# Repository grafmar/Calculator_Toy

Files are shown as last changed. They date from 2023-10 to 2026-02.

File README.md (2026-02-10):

# Calculator_Toy
Device for kids which generates math equations to solve. You can configure the following:
- Set the maximum numbers too choose from randomly (1 up to 9999)
- Set the operation to build:
  - Addition (+)
  - Substraction (-)
  - Multiplication (*)
  - Division (:)

## Required SW
* [Arduino IDE](https://www.arduino.cc/en/main/software)
* Adafruit_GFX library
* Adafruit SSD1306 library
* Keypad library

## Hardware
The hardware consists of:
* Perfboard 7x9 cm
* [Arduino Nano](https://store.arduino.cc/collections/nano-family/products/arduino-nano)
* [0.96" SSD1306 OLED display](https://www.aliexpress.com/w/wholesale-ssd1306.html)
* Tactile push buttons 6x6x8mm
* [Push Button Switch 7x7x12mm](https://www.aliexpress.com/item/32826123110.html)
* Buzzer

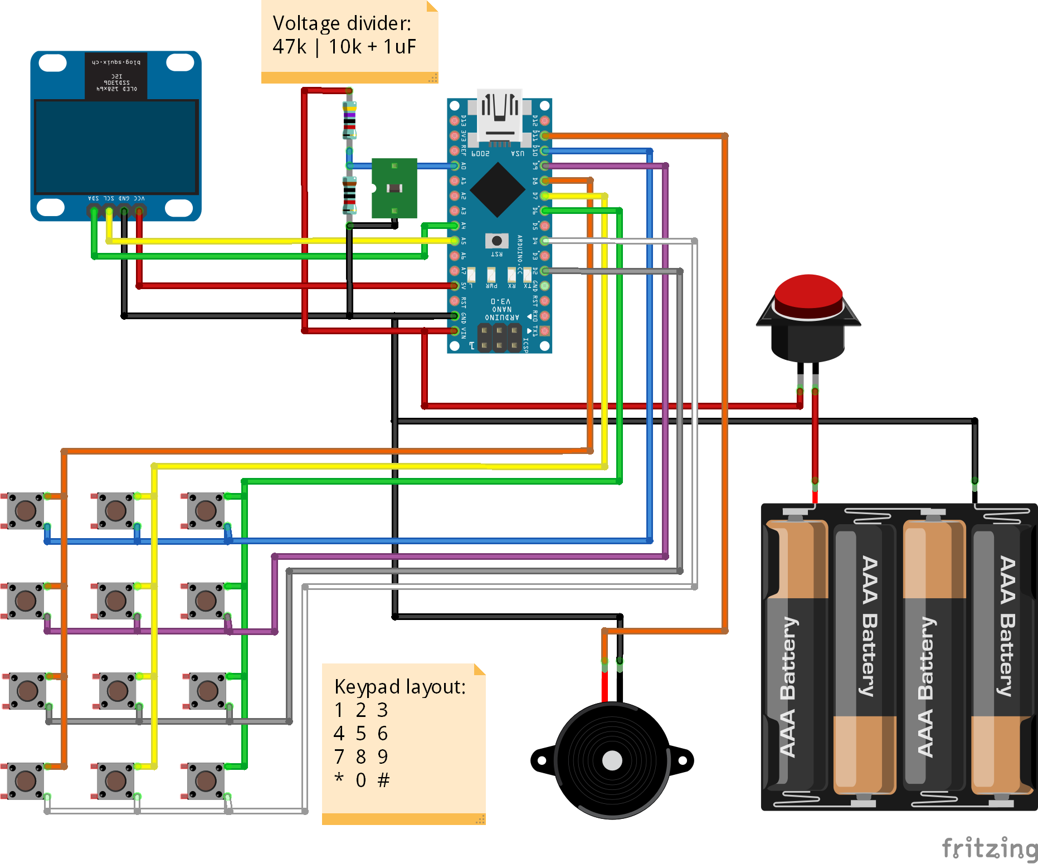
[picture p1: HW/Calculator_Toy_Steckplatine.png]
Wiring of hardware
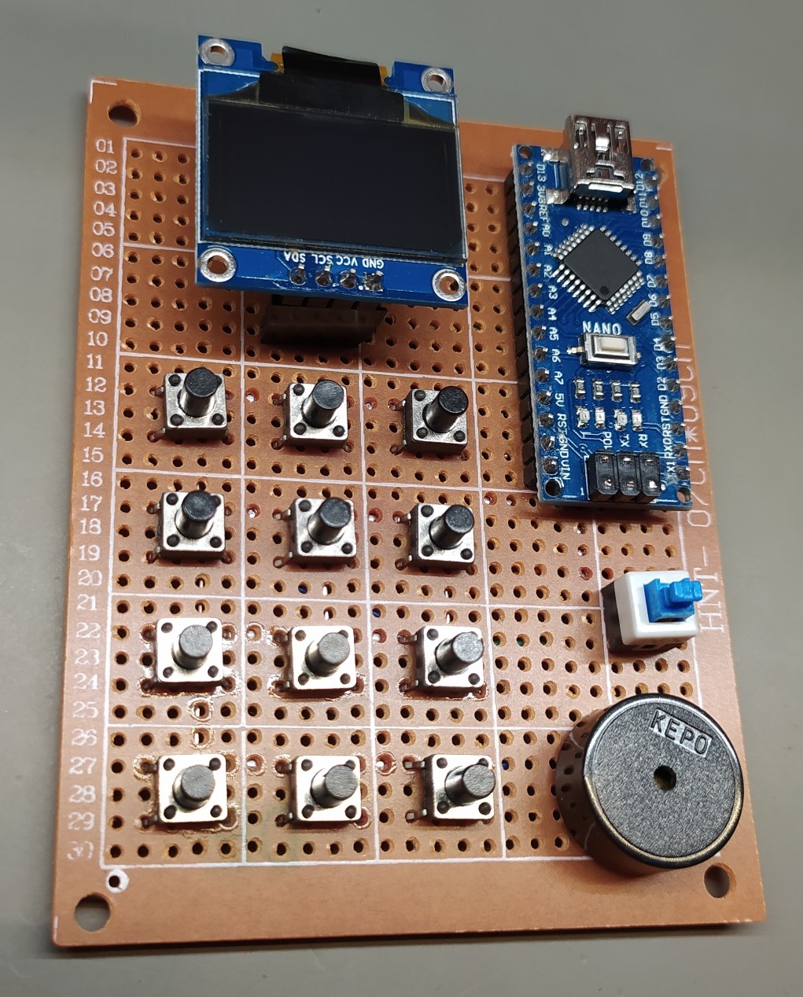
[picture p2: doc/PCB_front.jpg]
PCB front
 <br>

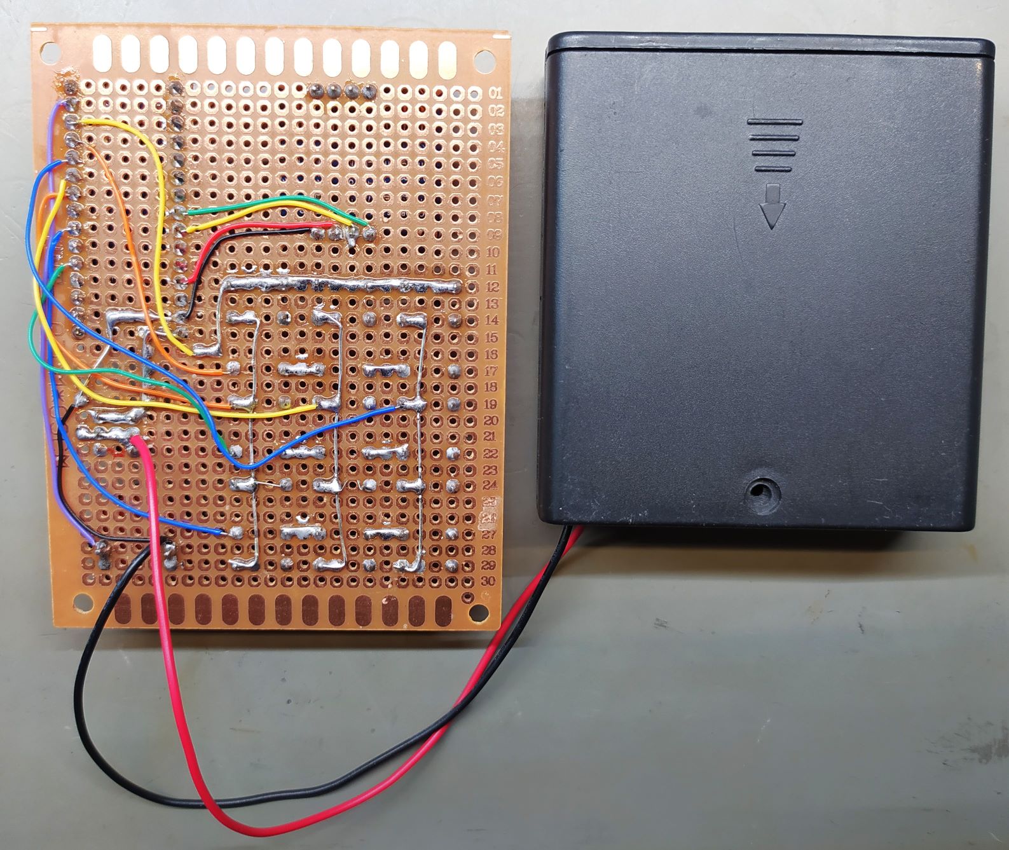
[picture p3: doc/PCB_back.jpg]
PCB back
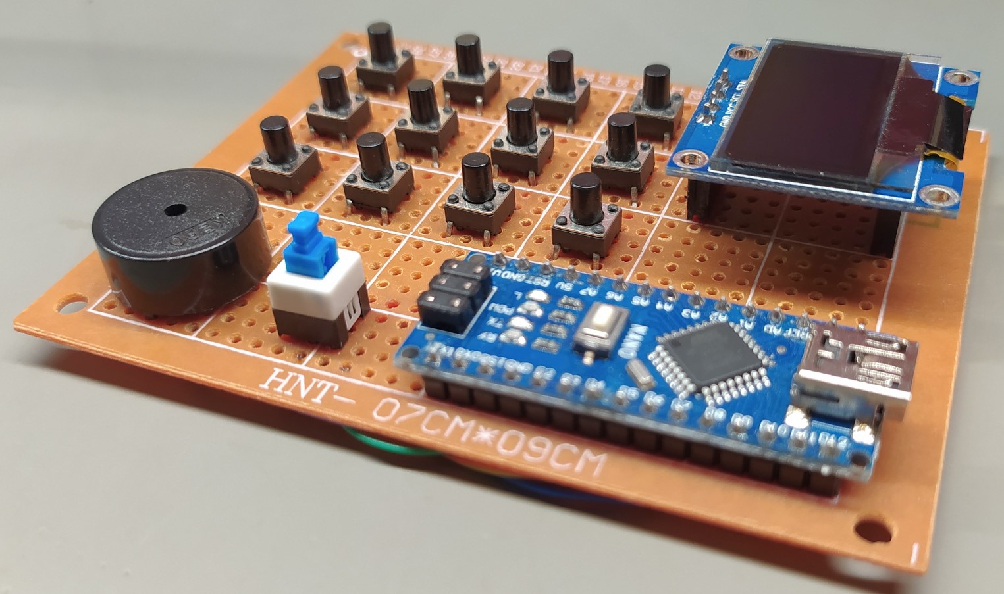
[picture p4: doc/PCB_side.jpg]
PCB side
 

The Display is supported with an additional pin-header on top, so the display is flush
to the housing.

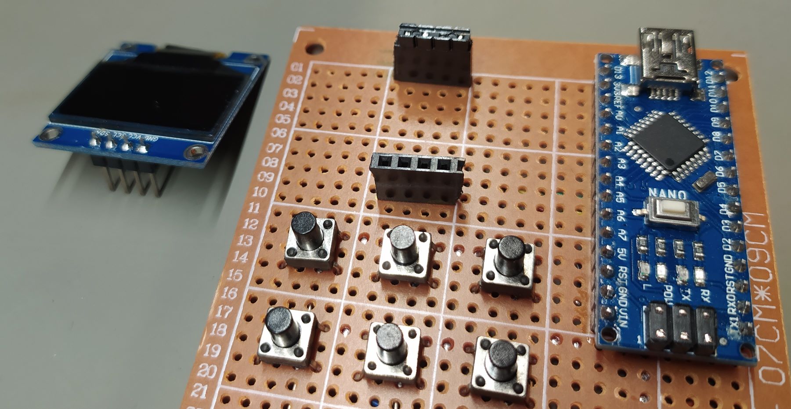
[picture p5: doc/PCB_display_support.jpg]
Display support


To monitor the battery a voltage divider has been added from Vin to the analog input A0
with 47k and 10k resistors and a 1uF capacitor.

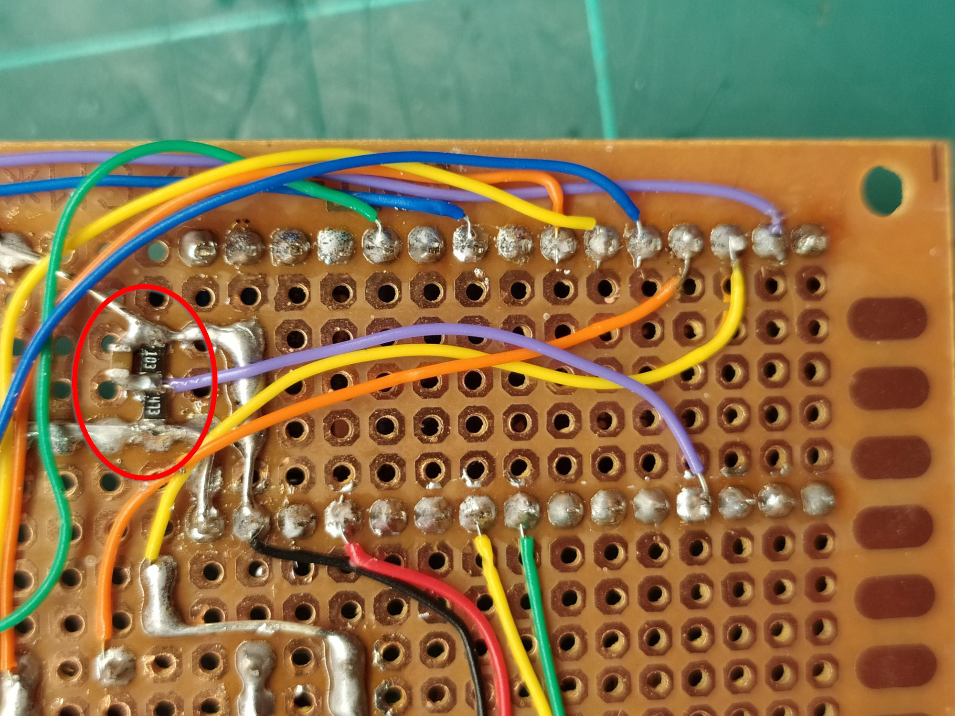
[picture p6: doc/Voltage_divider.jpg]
Added voltage divier


## Software
The software is compiled in Arduino IDE and uploaded to the Arduino Nano.
It was tricky to fit all the things into the memory of the Arduino Nano.

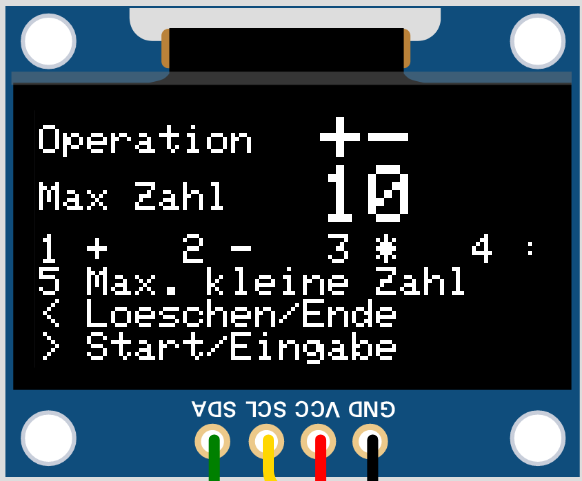
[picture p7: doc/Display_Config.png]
Display Config


First the configuration screeen is shown to configure which operations are used in the
game and how big the numbers may be. For the operations it can be choosen from plus,
minus, multiplication and division. The number-space is defined by defining the maximum
small numbers. So the sum, the minuend, the dividend and product may be bigger.

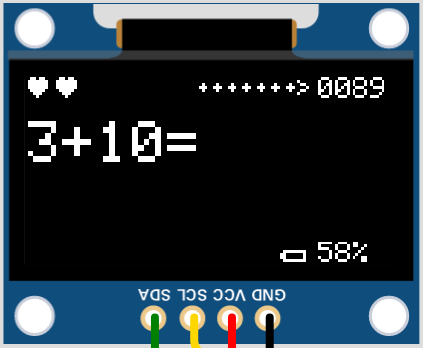
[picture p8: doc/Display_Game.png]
Display Game


Then the calculation game is started. There are three lives represented as hearts. If an
answer of the calculation is wrong, it costs a live. If the calculation is right, points
are earned. This depends on the time used to solve the calculation. Besides the score points
are shown which decrease the more time is needed. The remaining points are added to the
score if the right answer is given.

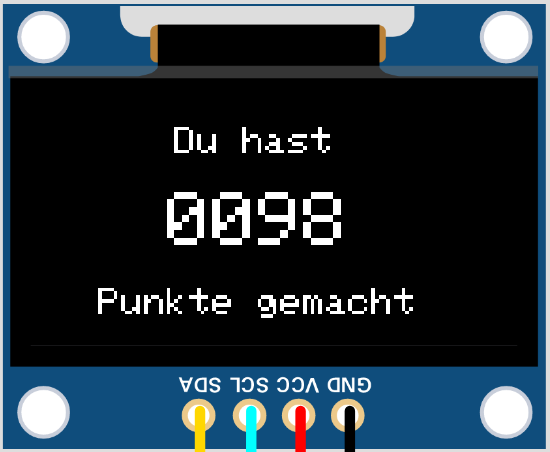
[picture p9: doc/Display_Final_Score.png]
Display Final Score


If the all lives were lost, the reached score is shown.

[Here is a life simulation of the circuit and code](https://wokwi.com/projects/378812103614159873)

## Housing / Enclosure
The housing is created with a sliding back to close the housing and support the PCB
for any button presses. The Buttons are designed with engraved numbers and symbols.

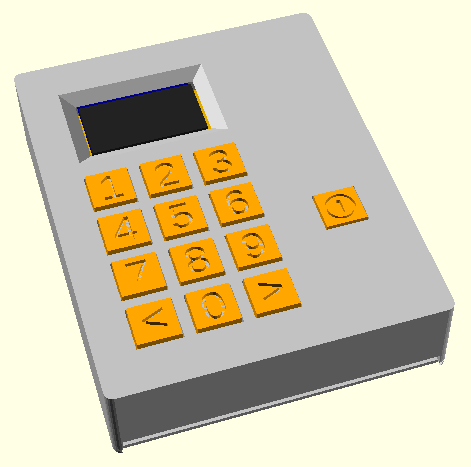
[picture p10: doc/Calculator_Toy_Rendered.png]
Rendered Housing
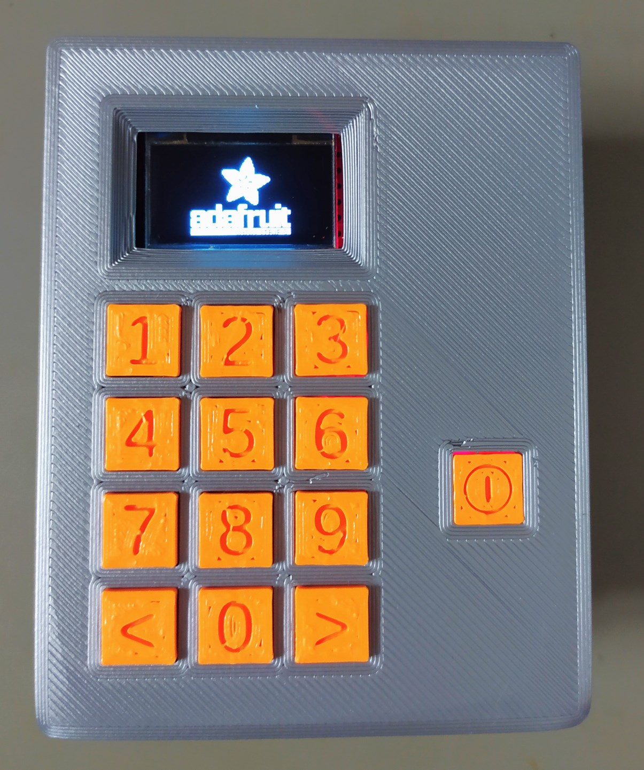
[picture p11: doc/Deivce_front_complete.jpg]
Finished device
 <br>

Added a lid to screw the housing shut and used filament change to add a second color for the inlets of the keys.

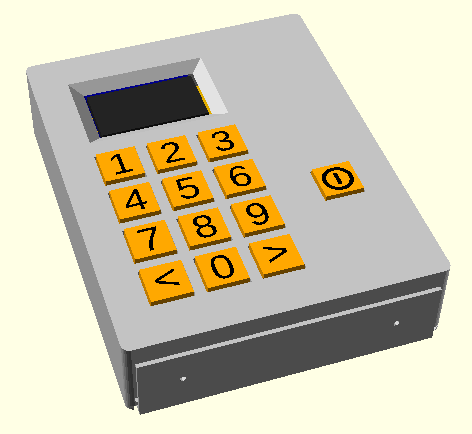
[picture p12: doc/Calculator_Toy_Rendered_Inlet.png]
Rendered Housing with inlet keys
<br>

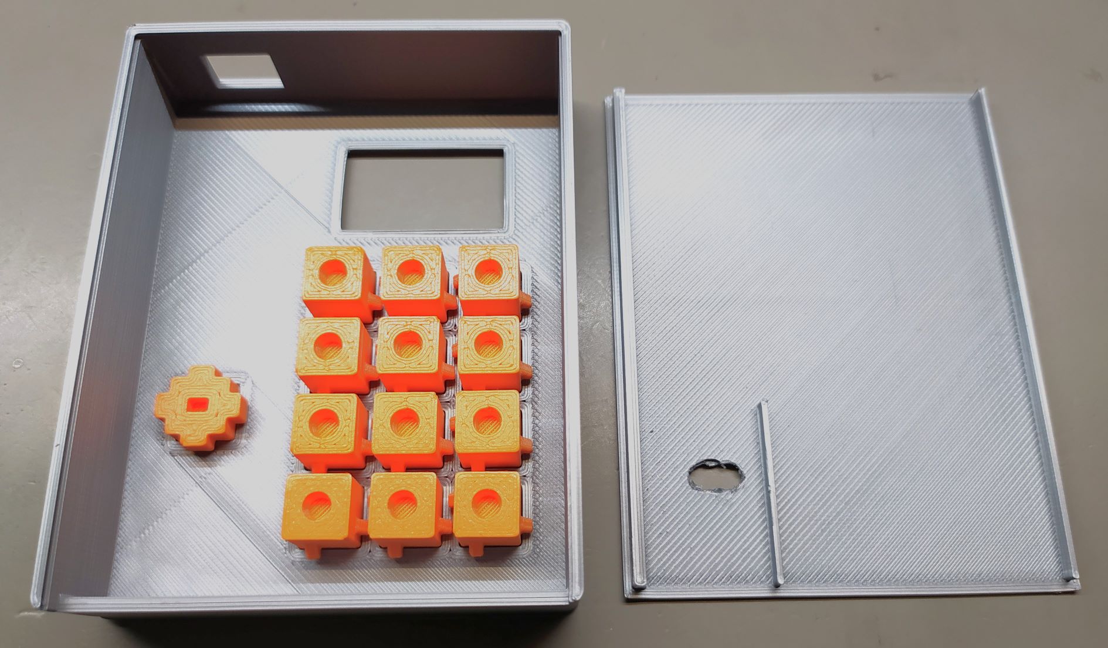
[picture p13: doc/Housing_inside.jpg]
Housing inside
<br>

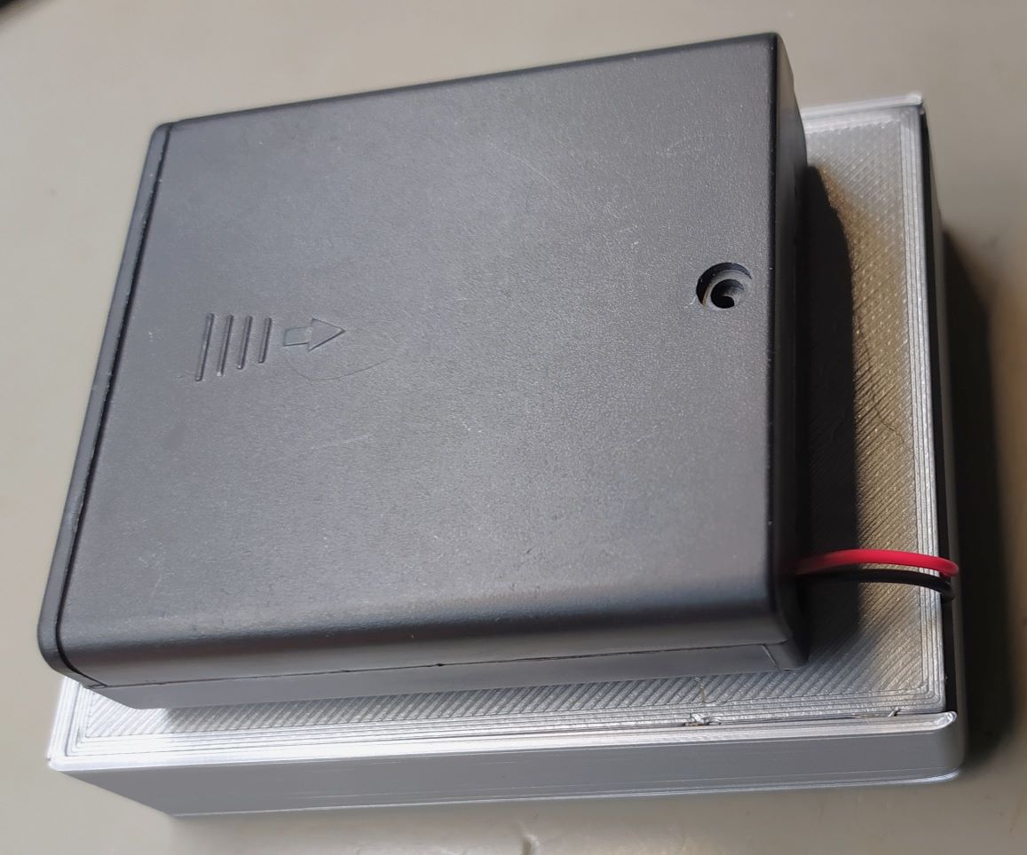
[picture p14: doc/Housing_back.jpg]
Housing back
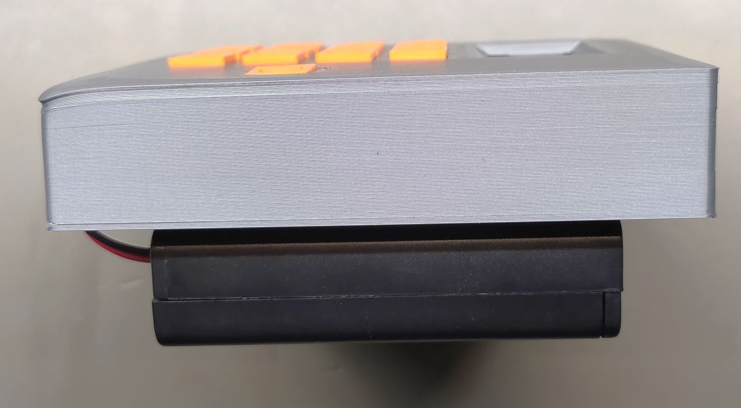
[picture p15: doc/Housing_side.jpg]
Housing side
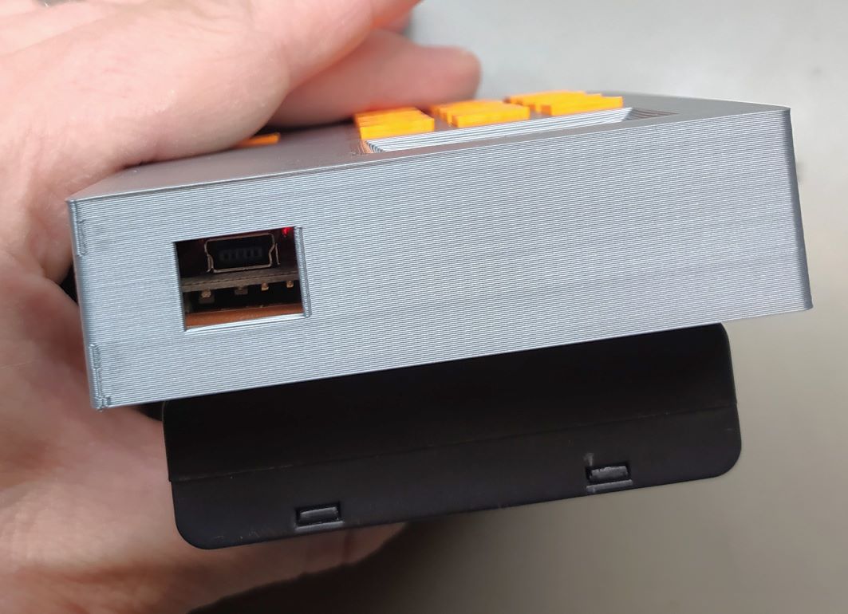
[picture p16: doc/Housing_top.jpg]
Housing top
  

## Author
[Marco Graf](https://github.com/grafmar)

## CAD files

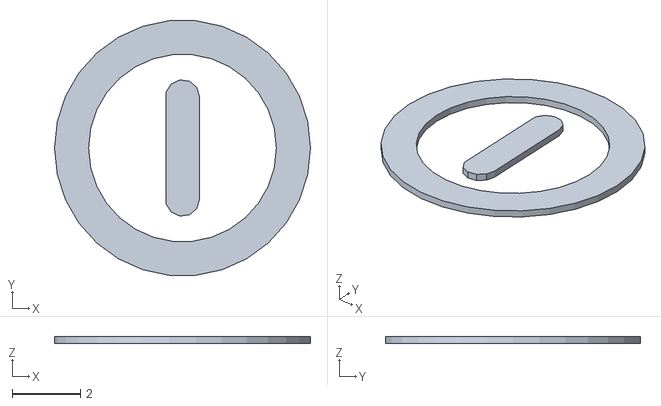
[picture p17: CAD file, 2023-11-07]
Housing/Calculator_Toy_OnOffSwitch_Inlet.stl
7.50 x 7.46 x 0.2

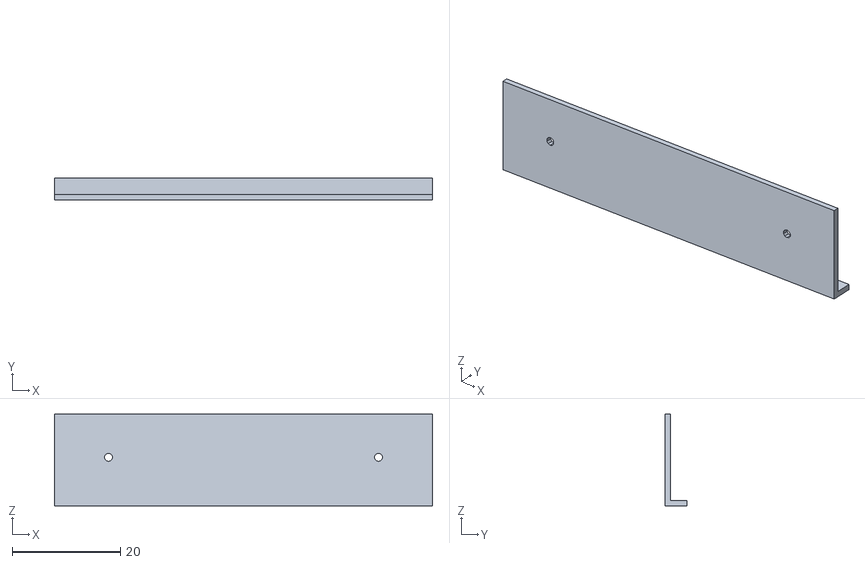
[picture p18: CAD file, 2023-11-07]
Housing/Calculator_Toy_Housing_closingLid.stl
70.0 x 4.00 x 17.0

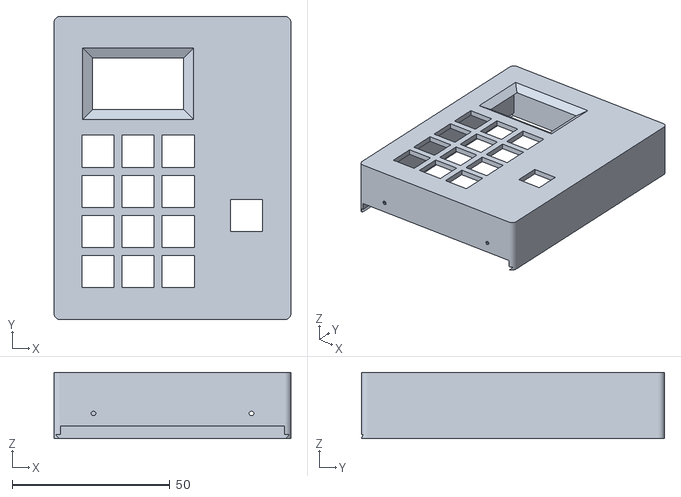
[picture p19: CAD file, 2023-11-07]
Housing/Calculator_Toy_Housing_Housing.stl
75.0 x 96.0 x 21.0

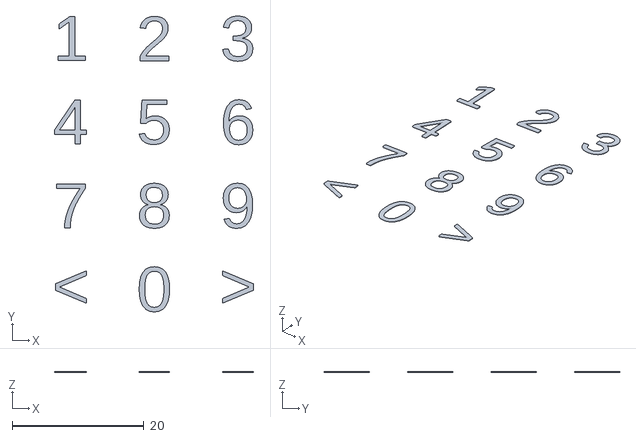
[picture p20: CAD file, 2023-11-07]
Housing/Calculator_Toy_Keypad_Inlet.stl
30.2 x 45.0 x 0.2

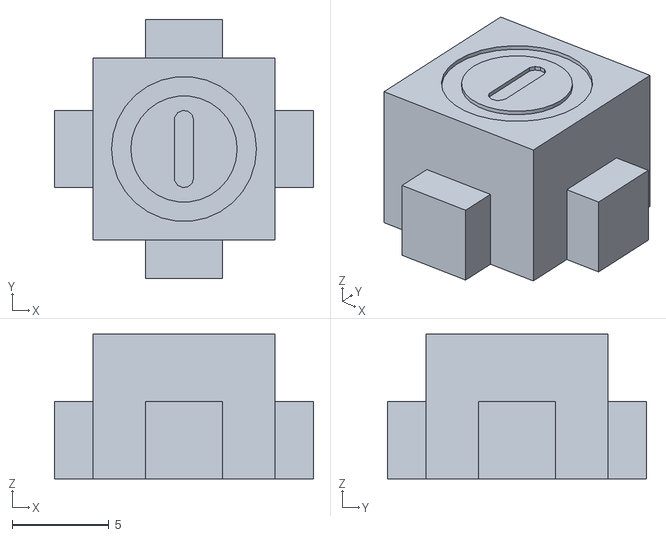
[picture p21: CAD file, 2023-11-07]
Housing/Calculator_Toy_OnOffSwitch_ForInlet.stl
13.4 x 13.4 x 7.50

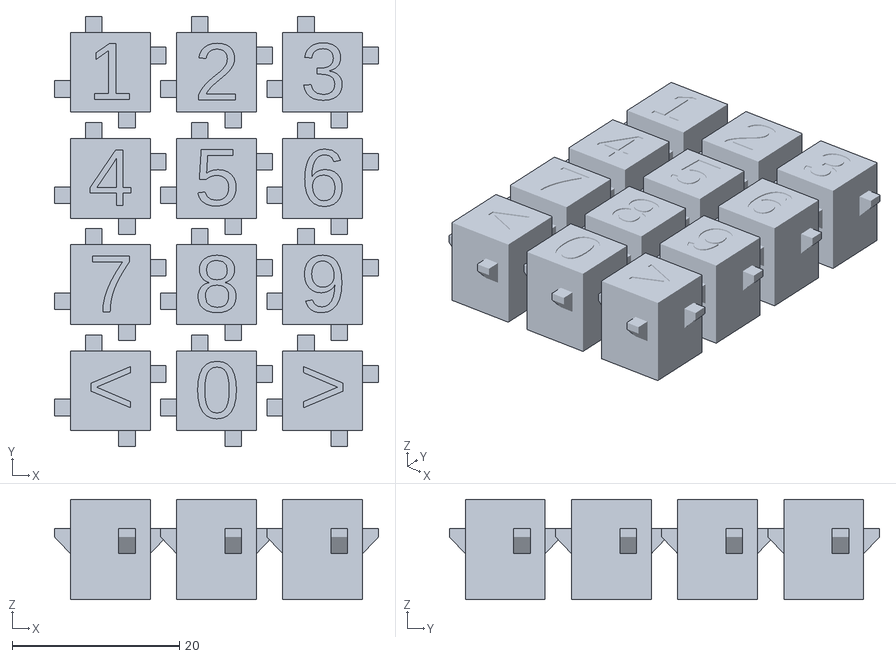
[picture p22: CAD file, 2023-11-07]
Housing/Calculator_Toy_Keypad_ForInlet.stl
38.8 x 51.5 x 12.0

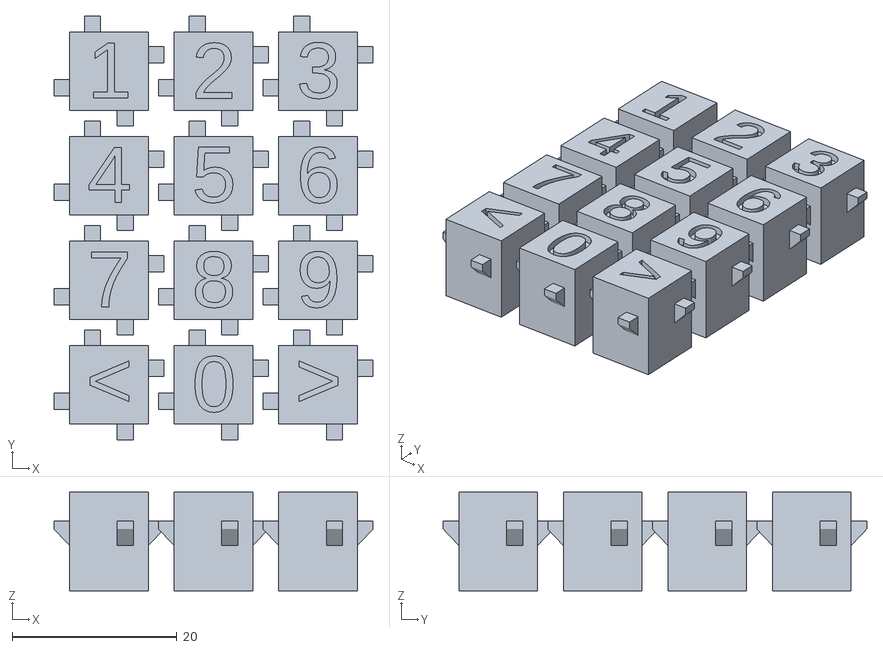
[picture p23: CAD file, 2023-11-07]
Housing/Calculator_Toy_Keypad_Embossed.stl
38.8 x 51.5 x 12.0

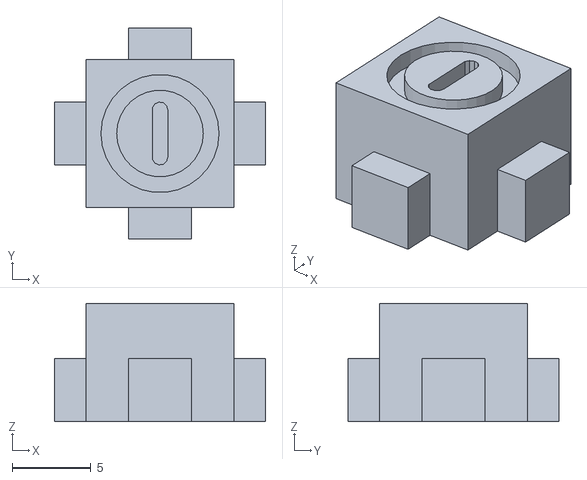
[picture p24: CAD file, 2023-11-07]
Housing/Calculator_Toy_OnOffSwitch_Embossed.stl
13.4 x 13.4 x 7.50

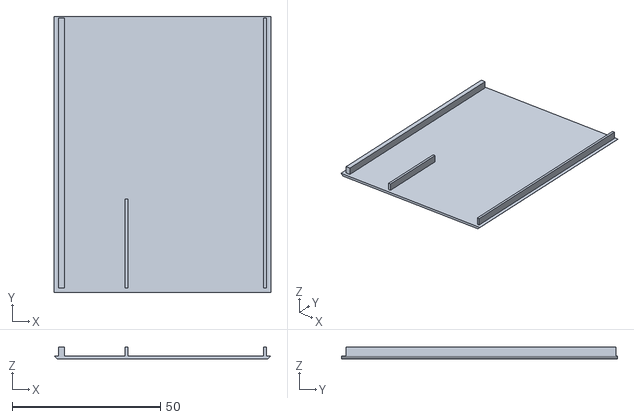
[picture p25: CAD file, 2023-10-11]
Housing/Calculator_Toy_Housing_slide.stl
73.0 x 93.0 x 4.01

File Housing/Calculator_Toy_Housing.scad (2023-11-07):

use <Calculator_Toy_PCB.scad>

buttonPos = [
[2.5,2,"<"], [7.5,2,"0"], [12.5,2,">"],
[2.5,7,"7"], [7.5,7,"8"], [12.5,7,"9"],
[2.5,12,"4"],[7.5,12,"5"],[12.5,12,"6"],
[2.5,17,"1"],[7.5,17,"2"],[12.5,17,"3"]];

buttonChar = [
"1","2","3",
"4","5","6",
"7","8","9",
"*","0","#"];

pcbW=70;
pcbH=91;

thick=2;
clearance=0.3;
inletHeight=0.2;

color("orange")OnOffSwitch(inletHeight); // for inlet
color("black")OnOffSwitchInlet(inletHeight); // the inlet
color("orange")Keypad(inletHeight); // for inlet
color("black")KeypadInlet(inletHeight); // the inlet

Calculator_Toy_PCB();
//color("orange")OnOffSwitch(); // embossed
//color("orange")Keypad(); // embossed
color("silver")Housing();
color("silver")BottomSlide_compl();
color("silver")ClosingLid();

module ClosingLid() {
    translate([0,-thick-1.5,-5-1])rotate([0,-90,-90])difference(){
        union(){
            cube([17,pcbW,1]);
            cube([1,pcbW,4]);
        }
        for(i=[-1,1])translate([16/2+1,pcbW/2+i*(pcbW/2-10),0])cylinder(d=1.5,h=3,center=true,$fs=.5);
    }
}

module BottomSlide_compl() {
    BottomSlide();
    translate([0,0,-5])cube([2,pcbH,5-1]);
    translate([pcbW-1,0,-5])cube([1,pcbH,5-1]);
    translate([(2+7)*2.54-0.5,0,-5])cube([1,30,5-1]);
}
module BottomSlide() {
    hull(){
        translate([-0.5-thick/2,-0.5-thick/2,-5.01+thick/2])cube([pcbW+1+2*thick/2,pcbH+1+thick/2,0.01]);
        translate([-0.5,-0.5-thick/2,-5.01])cube([pcbW+1,pcbH+1+thick/2,0.01]);
    }
}
module Housing() {
difference(){
    translate([-0.5-thick,-0.5-thick,-5])roundCube([pcbW+1+2*thick,pcbH+1+2*thick,14+thick+5],thick);

    translate([-0.5,-0.5,-5.01])cube([pcbW+1,pcbH+1,14+5]);
    
    // bottom slide
    translate([-0.5,-0.5-10,-1-5.01])cube([pcbW+1,pcbH+1+10,5]);
    hull()for(zz=[0,clearance])for(yy=[0,-10])for(i=[-1:1])translate([i*clearance,yy,zz])BottomSlide();
    
    // Display
    translate([(2+6)*2.54,(3+21)*2.54,0]){translate([-(27.5-4*2.54)/2-0.5*2.54,-0.5*2.54,0]){
        hull(){
            translate([0-0.5,5-0.5,14-0.1])cube([27.5+1,15+1,0.1]);
            translate([0-2*thick,5-2*thick,14+thick+0.1])cube([27.5+4*thick,15+4*thick,0.1]);
        }
    }}
    
    // USB
    translate([(2+17)*2.54,(3+15)*2.54,0]){
        color("#DDDDDD")translate([5.3-0.5*2.54-(12-7.5)/2,37.1-1.5*2.54,2.5+1.5-5/2])cube([12,9+20,9]);
    }
    
    // On/Off-Switch
    translate([(2+21)*2.54,(3+9)*2.54,0]){
        color("#0000DD")translate([-5,-5,0+3])cube([10,10,14+thick+1]);
    }
    
    // Keypad
    for(pos=buttonPos)translate([(2+pos.x-2)*2.54,(3+pos.y-2)*2.54,0])cube([4*2.54,4*2.54,2*14]);
    
    // Screw holes
    translate([0,-thick-1.5,-5-1])rotate([0,-90,-90])for(i=[-1,1])translate([16/2+1,pcbW/2+i*(pcbW/2-10),0])cylinder(d=1.5,h=30,center=true,$fs=.5);

}
}

module OnOffSwitch(embossDepth=1) {
    // On/Off-Switch
    color("#DDDDDD")translate([(2+21)*2.54,(3+9)*2.54,0]){
        for(a=[0:90:360-0.1])rotate([0,0,a])translate([5-clearance,-2,7+2+0.5])cube([2,4,13.5-9.5]);
            
        difference() {
            translate([-5+clearance,-5+clearance,7+2+0.5])cube([10-2*clearance,10-2*clearance,14+thick+1-(7+2+0.5)]);
            translate([-3/2-clearance,-2/2-clearance,0])cube([3+2*clearance,2+2*clearance,12.5]);
            // PowerSymbol
            translate([0,0,14+thick+1 - embossDepth]){
                hull(){
                    translate([0,-1.5,0])cylinder(d=1,h=40,$fs=0.3);
                    translate([0,1.5,0])cylinder(d=1,h=40,$fs=0.3);
                }
                difference() {
                    $fs=.5;
                    cylinder(d=7.5,h=40);
                    cylinder(d=5.5,h=40);
                }
            }
        }
    }
}

module OnOffSwitchInlet(embossDepth) {
    // On/Off-Switch
    translate([(2+21)*2.54,(3+9)*2.54,0.01]){
        union() {
            // PowerSymbol
            translate([0,0,14+thick+1 - embossDepth]){
                hull(){
                    translate([0,-1.5,0])cylinder(d=1,h=embossDepth,$fs=0.3);
                    translate([0,1.5,0])cylinder(d=1,h=embossDepth,$fs=0.3);
                }
                difference() {
                    $fs=.5;
                    cylinder(d=7.5,h=embossDepth);
                    translate([0,0,-embossDepth])cylinder(d=5.5,h=3*embossDepth);
                }
            }
        }
    }
}

module Keypad(embossDepth=1) {
    // Keypad
    for(pos=buttonPos)translate([(2+pos.x-2)*2.54,(3+pos.y-2)*2.54,5]){
        translate([2*2.54,2*2.54,-5])for(a=[0:90:360-0.1])rotate([0,0,a])translate([2*2.54-clearance-0.1,1,14-0.5-1])hull(){
            cube([2,2,1]);
            translate([0,0,-2])cube([0.1,2,0.1]);
        }
        difference() {
            translate([clearance,clearance,0])cube([4*2.54-2*clearance,4*2.54-2*clearance,14+thick+1-5]);
            translate([2*2.54,2*2.54,-0.01])cylinder(d1=5,d2=3.7,h=8-5,$fs=0.5);
            translate([2*2.54,2*2.54,14+thick+1-5-embossDepth])linear_extrude(height=10,center=false,convexity=10)text(pos[2],size=7, halign="center",valign="center");
        }
    }
}


module KeypadInlet(embossDepth) {
    // Keypad
    for(pos=buttonPos)translate([(2+pos.x-2)*2.54,(3+pos.y-2)*2.54,5]){
        translate([2*2.54,2*2.54,14+thick+1-5-embossDepth])linear_extrude(height=embossDepth,center=false,convexity=10)text(pos[2],size=7, halign="center",valign="center");
    }
}

module roundCube(dim,rad) {
    $fs=0.5;
    hull() {
        for(xx=[rad,dim.x-rad])for(yy=[rad,dim.y-rad])translate([xx,yy,0])cylinder(r=rad,h=dim.z);
    }
}

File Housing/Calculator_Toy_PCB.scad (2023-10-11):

buttonPos = [
[2.5,2], [7.5,2], [12.5,2],
[2.5,7], [7.5,7], [12.5,7],
[2.5,12],[7.5,12],[12.5,12],
[2.5,17],[7.5,17],[12.5,17]];

pcbW=70;
pcbH=91;

Calculator_Toy_PCB();

module Calculator_Toy_PCB(holes=false) {
pcb(holes);
buttons();
buzzer();
switch();
display();
arduino();
}

module pcb(holes) {
    translate([0,0,-1])
    color("#DDAA00")
    difference() {
        cube([pcbW,pcbH,1]);
        if (holes) for(xx=[0:23])for(yy=[0:29])translate([(2+xx)*2.54,(3+yy)*2.54,0])cylinder(d=0.8,h=3,$fn=3,center=true);
    }
}

module buttons() {
    for(pos=buttonPos)translate([(2+pos.x)*2.54,(3+pos.y)*2.54,0])button();
}

module button() {
    $fs=0.5;
    //translate([1.5*2.54,2.54,0]){
        color("#222222")translate([0,0,1])cylinder(d=3.5,h=8-1);
        color("#AAAAAA")translate([-3,-3,3])cube([6,6,0.5]);    
        color("#222222")translate([-3,-3,0])cube([6,6,3]);
        color("#AAAAAA")for(i=[-1,1])translate([-(3*2.54)/2,i*2.54,0])cube([3*2.54,0.5,1]);    
    //}
}

module buzzer() {
    translate([(2+20)*2.54,(3+2)*2.54,0])difference() {
        color("#222222")cylinder(d=17,h=8);
        translate([0,0,5])cylinder(d=2,h=8,$fs=0.5);
    }
}

module switch(){
    translate([(2+21)*2.54,(3+9)*2.54,0]){
        color("#222222")translate([0,0,2])cube([7,7,4],center=true);
        color("#DDDDDD")translate([0,0,2+4])cube([7,7,4],center=true);
        color("#0000DD")translate([0,0,2+8])cube([3.5,3.5,4],center=true);
    }
}

module display(){
    translate([(2+6)*2.54,(3+21)*2.54,0]){
        translate([-(27.5-4*2.54)/2-0.5*2.54,-0.5*2.54,0]){
            color("#000088")translate([0,0,11])cube([27.5,28,1]);
            color("#222222")translate([0,5,12])cube([27.5,15,2]);
        }
        color("#222222")translate([-0.5*2.54,-0.5*2.54,0])cube([4*2.54,2.54,11]);
    }
}

module arduino(){
    translate([(2+17)*2.54,(3+15)*2.54,0]){
        color("#222222")translate([-0.5*2.54,-0.5*2.54,0])cube([2.54,15*2.54,2.5]);   
        color("#222222")translate([(6-0.5)*2.54,-0.5*2.54,0])cube([2.54,15*2.54,2.5]);   
        color("#000088")translate([-0.5*2.54,-1.5*2.54,2.5])cube([7*2.54,17*2.54,1]);
        color("#DDDDDD")translate([5.3-0.5*2.54,37.1-1.5*2.54,2.5+1.5])cube([7.5,9,4]);
    }
}

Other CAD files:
Housing/Calculator_Toy_KeypadCaps.stl

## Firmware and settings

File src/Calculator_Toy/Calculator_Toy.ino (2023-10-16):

/*
  Calculator Toy

  Tool for kids wich displays math equations to solve

  circuit:
  - 3x4 button keypad matrix
  - ssd1306 OLED display
  - buzzer

  created 2023-09-20
  by Marco Graf

  https://github.com/grafmar/Calculator_Toy
*/

#include "KeypadReader.h"
#include "Game.h"

KeypadReader keypadReader;
Game game;

void setup() {
  game.begin();
}

void loop() {
  game.handle(keypadReader.getKey());
}

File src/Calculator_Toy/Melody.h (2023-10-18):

/**
 ******************************************************************************
 * \file Melody.h
 *
 * \par<b>Detailed Description:</b>
 * Definition of a melody with its name, bpm, frequencies and durations.
 ******************************************************************************
 */
#ifndef MELODY_H
#define MELODY_H

#include <Arduino.h>

/******************************************************************************
 ** Constants, Makros and type definitions                                   **
 ******************************************************************************/

/// Shifts the given frequency (of octave 4) to the given octave
#define MEL_TONE_SHIFT_TO_OCTAVE(freq, x)   (((x >= 4) ? (freq << (x-4)) : (freq >> (4-x)))/8) // divide by 8, later multiply

/// Tone definition C  . Use octave number as parameter MEL_TONE_A(4) -> 440 Hz
#define MEL_TONE_C(x)                       MEL_TONE_SHIFT_TO_OCTAVE(262, x)
/// Tone definition C  . Use octave number as parameter MEL_TONE_A(4) -> 440 Hz
#define MEL_TONE_CIS(x)                     MEL_TONE_SHIFT_TO_OCTAVE(277, x)
/// Tone definition C  . Use octave number as parameter MEL_TONE_A(4) -> 440 Hz
#define MEL_TONE_D(x)                       MEL_TONE_SHIFT_TO_OCTAVE(294, x)
/// Tone definition C  . Use octave number as parameter MEL_TONE_A(4) -> 440 Hz
#define MEL_TONE_DIS(x)                     MEL_TONE_SHIFT_TO_OCTAVE(311, x)
/// Tone definition C  . Use octave number as parameter MEL_TONE_A(4) -> 440 Hz
#define MEL_TONE_E(x)                       MEL_TONE_SHIFT_TO_OCTAVE(330, x)
/// Tone definition C  . Use octave number as parameter MEL_TONE_A(4) -> 440 Hz
#define MEL_TONE_F(x)                       MEL_TONE_SHIFT_TO_OCTAVE(349, x)
/// Tone definition C  . Use octave number as parameter MEL_TONE_A(4) -> 440 Hz
#define MEL_TONE_FIS(x)                     MEL_TONE_SHIFT_TO_OCTAVE(370, x)
/// Tone definition C  . Use octave number as parameter MEL_TONE_A(4) -> 440 Hz
#define MEL_TONE_G(x)                       MEL_TONE_SHIFT_TO_OCTAVE(392, x)
/// Tone definition C  . Use octave number as parameter MEL_TONE_A(4) -> 440 Hz
#define MEL_TONE_GIS(x)                     MEL_TONE_SHIFT_TO_OCTAVE(415, x)
/// Tone definition C  . Use octave number as parameter MEL_TONE_A(4) -> 440 Hz
#define MEL_TONE_A(x)                       MEL_TONE_SHIFT_TO_OCTAVE(440, x)
/// Tone definition C  . Use octave number as parameter MEL_TONE_A(4) -> 440 Hz
#define MEL_TONE_AIS(x)                     MEL_TONE_SHIFT_TO_OCTAVE(466, x)
/// Tone definition C  . Use octave number as parameter MEL_TONE_A(4) -> 440 Hz
#define MEL_TONE_H(x)                       MEL_TONE_SHIFT_TO_OCTAVE(494, x)

/// Define a puase as freqency 0 Hz
#define MEL_PAUSE                           0

#define MEL_NOTE_4TH        (232/2)                                               ///< 1/4 Note length (232ms refers to ~259 BPM) divided by 2 to later multiply
#define MEL_NOTE_8TH        (MEL_NOTE_4TH / 2)                                  ///< 1/8 Note length
#define MEL_NOTE_16TH       (MEL_NOTE_4TH / 4)                                  ///< 1/16 Note length
#define MEL_NOTE_32TH       (MEL_NOTE_4TH / 8)                                  ///< 1/32 Note length
#define MEL_NOTE_2TH        (MEL_NOTE_4TH * 2)                                  ///< 1/2 Note length
#define MEL_NOTE_1TH        (MEL_NOTE_4TH * 4)                                  ///< Full Note length
#define MEL_NOTE_HALF       (MEL_NOTE_4TH * 2)                                  ///< 1/2 Note length
#define MEL_NOTE_FULL       (MEL_NOTE_4TH * 4)                                  ///< 1/1 Note length

#define MEL_NOTE_4TH_DOT    (MEL_NOTE_4TH  + MEL_NOTE_8TH)                      ///< dotted 1/4 Note length
#define MEL_NOTE_8TH_DOT    (MEL_NOTE_8TH  + MEL_NOTE_16TH)                     ///< dotted 1/8 Note length
#define MEL_NOTE_16TH_DOT   (MEL_NOTE_16TH + MEL_NOTE_32TH)                     ///< dotted 1/16 Note length
#define MEL_NOTE_32TH_DOT   (MEL_NOTE_32TH + MEL_NOTE_32TH/2)                   ///< dotted 1/32 Note length
#define MEL_NOTE_2TH_DOT    (MEL_NOTE_2TH  + MEL_NOTE_4TH)                      ///< dotted 1/2 Note length
#define MEL_NOTE_1TH_DOT    (MEL_NOTE_1TH  + MEL_NOTE_2TH)                      ///< dotted 1/1 Note length
#define MEL_NOTE_HALF_DOT   (MEL_NOTE_HALF + MEL_NOTE_4TH)                      ///< dotted 1/2 Note length
#define MEL_NOTE_FULL_DOT   (MEL_NOTE_FULL + MEL_NOTE_2TH)                      ///< dotted 1/1 Note length

#endif // MELODY_H

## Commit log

2023-09-20 Housing first stage
    [Calculator_Toy_Housing.scad, Calculator_Toy_PCB.scad]
2023-09-29 Added fizzing schematic
    [Calculator_Toy.fzz]
2023-10-11 completed housing
    [Calculator_Toy_Housing.scad, Calculator_Toy_Housing_Housing.stl, Calculator_Toy_Housing_slide.stl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]
2023-10-16 updated fritzzing schematic with battery and switch
    [Calculator_Toy.fzz]
2023-10-18 Added Lid to lock the carriage back
    [Calculator_Toy_Housing_closingLid.scad, Calculator_Toy_Housing_closingLid.stl]
2023-10-21 Implementation of BatteryMonitor simplified melodies for good and bad
2023-10-21 Added voltage divider for BatteryMonitor to the frizzing schematic
    [Calculator_Toy.fzz]
2023-10-21 Added picture and description for voltage divider
2023-10-21 updated screen with battery monitoring
2023-11-07 Added a closing lid and keys with inlet
    [Calculator_Toy_Housing.scad, Calculator_Toy_Housing_Housing.stl, Calculator_Toy_Housing_closingLid.scad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]
